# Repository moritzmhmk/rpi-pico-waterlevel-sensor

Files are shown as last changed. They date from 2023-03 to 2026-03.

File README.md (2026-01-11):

# rpi-pico-waterlevel-sensor

## Hardware

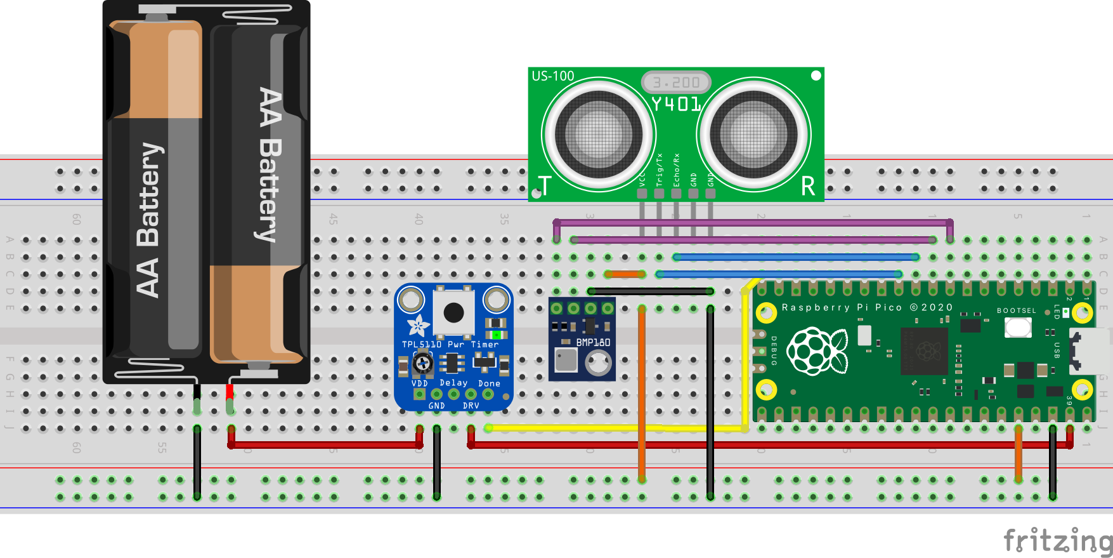
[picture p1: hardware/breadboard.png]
Breadboard setup


## Setup Development Environment

Create venv:

```bash
$ python3 -m venv .venv
$ source .venv/bin/activate
```

Install stubs:

```bash
$ pip install micropython-rp2-stubs
```

## Install dependencies on device

Install mpremote

```bash
$ pip install mpremote
```

```bash
$ mpremote connect port:/dev/tty.usbmodem14101 mip install umqtt.simple
$ mpremote connect port:/dev/tty.usbmodem14101 mip install github:robert-hh/BME280/bme280_float.py
```

### Setup Home Assistant
```bash
$ mosquitto_pub -h homeassistant.local -u <USER> -P <PASSWORD> -t "homeassistant/device/waterlevel_01/config" -r -f homeassistant_config.json
```
To remove publish an empty message (calling with `-n` instead of `-f homeassistant_config.json`).

### Setup Homebridge

Add accessory to `config.json` of homebridge:

```json
{
    "bridge": {...},
    "accessories": [
        ...,
        {
            "type": "leakSensor",
            "name": "Water Level Sensor 01",
            "url": "broker.emqx.io",
            "logMqtt": true,
            "codec": "waterlevel.js",
            "topics": {
                "getOnline": "moritzmhmk/sensor_01",
                "getBatteryLevel": "moritzmhmk/sensor_01",
                "getLeakDetected": "moritzmhmk/sensor_01",
                "getWaterLevel": "moritzmhmk/sensor_01",
            },
            "accessory": "mqttthing"
        }
    ],
    "platforms": [...]
}
```

Create "codec" file `waterlevel.js` in the same path as the config.json.

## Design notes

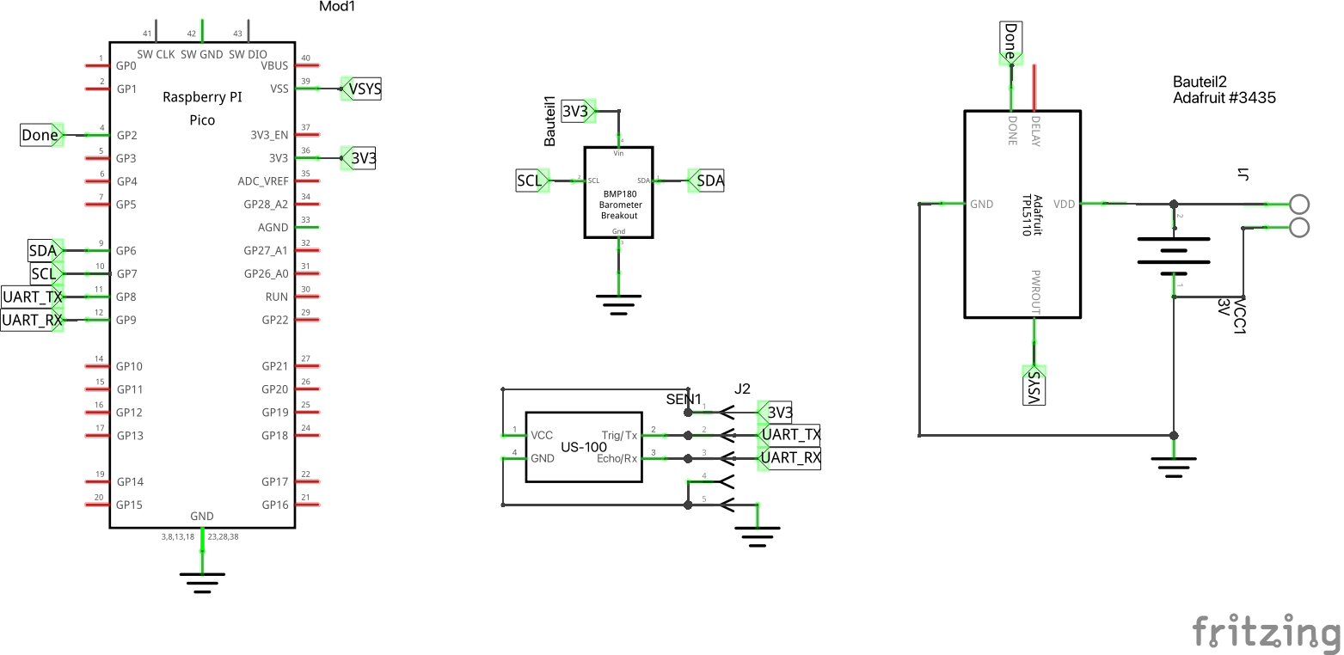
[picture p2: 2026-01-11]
hardware/schema.png

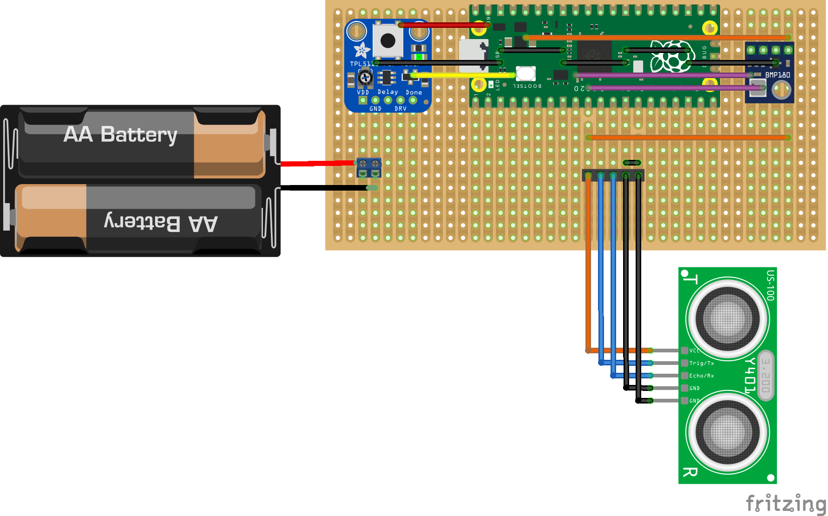
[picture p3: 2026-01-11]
hardware/stripboard.png

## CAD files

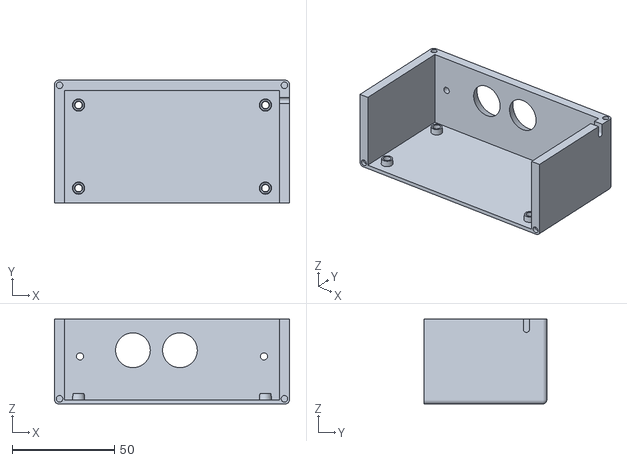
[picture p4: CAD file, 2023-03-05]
case_base.stl
115.0 x 60.0 x 41.5

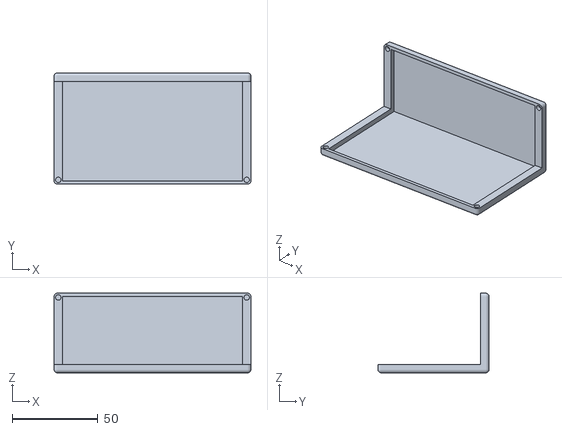
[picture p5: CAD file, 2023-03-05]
case_cover.stl
115.0 x 65.0 x 46.5

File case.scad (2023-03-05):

$fn=64;

us_o_d = 12; // offset of ultrasonic sensor in depth direction
us_o_w = 3*2.54; // offset of ultrasonic sensor in width direction
us_d = 16.5; // diameter of ultrasonic sensor tubes

module rounded_cube(size, r, center) {
  translate(center ? [0,0,0] : [r,r,r]) minkowski() {
    cube([size[0]-2*r, size[1]-2*r, size[2]-2*r], center);
    sphere(r=r);
  }
}

pcb_o = 3 + 3; // pcb offset = thickness of wall + standoff
w = 115;
h = 65;
d = pcb_o+us_o_d+us_d+us_o_d;

module magnet_holes() {
  mh = 2.2;
  md = 3.2;

  translate([2.5,2.5,h-5-2]) cylinder(d=md, h=2*mh);
  translate([2.5,d-5-2,2.5]) rotate([-90]) cylinder(d=md, h=2*mh);
  
  translate([w-2.5,2.5,h-5-2]) cylinder(d=md, h=2*mh);
  translate([w-2.5,d-5-2,2.5]) rotate([-90]) cylinder(d=md, h=2*mh);
}

module heat_insert() {
  cylinder(d=3.5, h=3);
  translate([0,0,2]) cylinder(d1=3.5, d2=4, h=3.1);
}

module standoff() {
  translate([0,0,2]) cylinder(d1=6, d2=5.5, h=3);
}

pcb_w = 36*2.54;
pcb_h = 16*2.54;

module case_base() difference() {
  union() {
    difference() {
      rounded_cube([w,d,h], 2);
      translate([5,2,5]) cube([w-10, d-2, h-5]);
      translate([0,d-5,0]) cube([w, 100, 100]);
      translate([0,0,h-5]) cube([w, 100, 100]);
    }

    translate([(w-pcb_w)/2,0,(h-pcb_h)/2]) rotate([-90]) standoff();
    translate([(w+pcb_w)/2,0,(h-pcb_h)/2]) rotate([-90]) standoff();
    translate([(w-pcb_w)/2,0,(h+pcb_h)/2]) rotate([-90]) standoff();
    translate([(w+pcb_w)/2,0,(h+pcb_h)/2]) rotate([-90]) standoff();
  }
  translate([(w-pcb_w)/2,0,(h-pcb_h)/2]) rotate([-90]) heat_insert();
  translate([(w+pcb_w)/2,0,(h-pcb_h)/2]) rotate([-90]) heat_insert();
  translate([(w-pcb_w)/2,0,(h+pcb_h)/2]) rotate([-90]) heat_insert();
  translate([(w+pcb_w)/2,0,(h+pcb_h)/2]) rotate([-90]) heat_insert();
  
  // ultrasonic tube holes
  translate([(w-6.5-us_d)/2-us_o_w,pcb_o+us_d/2+us_o_d,0]) cylinder(d1=us_d+4, d2=us_d+0.5, h=5);
  translate([(w+6.5+us_d)/2-us_o_w,pcb_o+us_d/2+us_o_d,0]) cylinder(d1=us_d+4, d2=us_d+0.5, h=5);
  
  // bottom mounting holes
  translate([(w-90)/2,d/2,0]) cylinder(d=3.5, h=100);
  translate([(w+90)/2,d/2,0]) cylinder(d=3.5, h=100);
  
  // cable slot
  hull() {
    translate([w-10,d-10,10]) rotate([0,90]) cylinder(d=3, h=100);
    translate([w-10,d,10]) rotate([0,90]) cylinder(d=3, h=100);
  }
  
  
  magnet_holes();
}

module case_cover() difference() {
  rounded_cube([w,d,h], 2);
  translate([5,2,2]) cube([w-10, d-4, h-4]);
  cube([w, d-5, h-5]);
  magnet_holes();
}

rotate([90,0,0]) case_base();
// rotate([-90,0,0]) case_cover();

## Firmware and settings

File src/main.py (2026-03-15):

import json
import socket
import struct
import time

import bme280_float as bme280
import machine
import network
from machine import I2C, RTC, UART, Pin
from umqtt.simple import MQTTClient

import env


def read_vsys() -> float:
    # source: https://forums.raspberrypi.com/viewtopic.php?t=339994#p2036717
    _adc_max_value = 65535  # max value of 16bit unsinged
    _adc_ref_voltage = 3.3  # 3.3V reference voltage
    _vsys_divider = 3.0
    conversion_factor = (_adc_ref_voltage / _adc_max_value) * _vsys_divider

    def setPad(gpio, value):
        machine.mem32[0x4001C000 | (4 + (4 * gpio))] = value

    def getPad(gpio):
        return machine.mem32[0x4001C000 | (4 + (4 * gpio))]

    oldpad = getPad(29)
    setPad(29, 128)  # no pulls, no output, no input
    adc_Vsys = machine.ADC(3)
    vsys = adc_Vsys.read_u16() * conversion_factor
    setPad(29, oldpad)
    return vsys


def connect_to_network(nic: network.WLAN, ssid: str, password: str):
    print(f'Connecting to network "{ssid}"...', end="")
    nic.active(True)
    nic.connect(ssid, password)
    for _ in range(10):
        s = nic.status()
        if s == 3:
            print(" done.")
            break
        if s >= 0:
            time.sleep(1)
            print(".", end="")
            continue
        if s == -1:
            print(" failed!")
        if s == -2:
            print(" no network!")
        if s == -3:
            print(" bad authentication!")

        raise RuntimeError("Network connection failed.")


def set_time_from_ntp(host: str = "pool.ntp.org"):
    NTP_DELTA = 2208988800
    NTP_QUERY = bytearray(48)
    NTP_QUERY[0] = 0x1B
    addr = socket.getaddrinfo(host, 123)[0][-1]
    s = socket.socket(socket.AF_INET, socket.SOCK_DGRAM)
    try:
        s.settimeout(1)
        s.sendto(NTP_QUERY, addr)
        msg = s.recv(48)
    finally:
        s.close()
    val = struct.unpack("!I", msg[40:44])[0]
    t = val - NTP_DELTA
    tm = time.gmtime(t)
    RTC().datetime((tm[0], tm[1], tm[2], tm[6] + 1, tm[3], tm[4], tm[5], 0))


def time_to_iso(t: time.struct_time):
    Y, m, d, H, M, S, *_ = t
    return f"{Y}-{m:02}-{d:02}T{H:02}:{M:02}:{S:02}Z"


def us100_read_distance(uart: UART) -> float | None:
    for _ in range(2):
        uart.write(b"\x55")
        time.sleep(0.1)
        data = uart.read(2)
        if data and len(data) == 2:
            return (data[1] + (data[0] << 8)) / 10
        time.sleep(0.1)
    return None


def us100_read_temperature(uart: UART) -> int | None:
    for _ in range(2):
        uart.write(b"\x50")
        time.sleep(0.1)
        data = uart.read(1)
        if data and len(data) == 1:
            return data[0] - 45
        time.sleep(0.1)
    return None


if __name__ == "__main__":
    led_pin = Pin("LED", mode=Pin.OUT, value=1)
    done_pin = Pin(2, mode=Pin.OUT, value=0)
    try:
        battery_voltage = read_vsys()

        i2c = I2C(1, sda=Pin(6), scl=Pin(7))
        bme = bme280.BME280(i2c=i2c)
        bme.read_compensated_data()  # discard first measurement
        temperature, pressure, humidity = bme.read_compensated_data()

        uart1 = UART(1, baudrate=9600, tx=Pin(8), rx=Pin(9))
        distances = []
        for _ in range(9):
            distances.append(us100_read_distance(uart1))
        distances.sort()
        distance = distances[4]  # the median of 9 measurements

        wlan = network.WLAN(network.STA_IF)
        connect_to_network(wlan, env.WLAN_SSID, env.WLAN_PASSWORD)

        set_time_from_ntp()
        timestamp = time_to_iso(time.gmtime())

        # MQTT
        client = MQTTClient(
            env.MQTT_CLIENT_ID,
            env.MQTT_SERVER,
            user=env.MQTT_USER,
            password=env.MQTT_PASSWORD,
            keepalive=3600,
        )

        client.connect()
        print(f'Connected to mqtt on "{env.MQTT_SERVER}" as "{env.MQTT_CLIENT_ID}".')
        payload = {
            "distance": distance,
            "temperature": temperature,
            "humidity": humidity,
            "pressure": pressure,
            "timestamp": timestamp,
            "batteryVoltage": battery_voltage,
        }
        topic = f"{env.MQTT_STATE_TOPIC}"
        client.publish(topic, json.dumps(payload), retain=True)
        print(f'Published payload "{payload}" in topic "{topic}".')
        client.disconnect()
        print("Disconnected from mqtt server.")
    except Exception as e:
        print(f"Exception {e} occured.")
        print(e)
    finally:
        # Blink LED
        for _ in range(5 * 2):
            led_pin.toggle()
            time.sleep(0.1)

        # Signal TPL5110 to shutdown power
        while True:
            led_pin.toggle()
            done_pin.toggle()
            time.sleep(0.5)

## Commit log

2023-02-26 read battery voltage
2023-03-04 Change done pin.
2023-03-05 Add case.
    [case.scad, case_base.stl, case_cover.stl]
2023-03-10 Add environment sensor fields to codec.
2026-01-11 Add hardware files.
    [breadboard.fzz, stripboard.fzz]
